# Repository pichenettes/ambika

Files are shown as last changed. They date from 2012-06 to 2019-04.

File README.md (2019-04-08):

# Ambika
## A hybrid MIDI polysynth and voicecard host.

Ambika consists of a compact motherboard serving as a "host" for up to 6 sound synthesis voicecard. While this design is primarily intended to be a flexible hybrid polysynth, it could also be used as a drum module/drum machine.

The motherboard comprises 6 audio outputs, each one connected to a voicecard ; a global mono output ; a pair of MIDI input/output ; a SD card slot ; a 5V/8V/-8V power supply capable of delivering 150mA on the 8V rails and 350mA on the 5V rail ; the master MCU and the user interface elements. The voicecards (a pair of each being attached to the 3 voicecard ports) are SPI slaves, they receive note and modulation data from the motherboard ; and output monophonic audio, ideally 1V pp.

3 designs of voicecards implementing a refined version of the Shruthi-1 engine are provided. Each of those use a different filter (4-Pole with LM13700, 4-Pole with SSM2164, 2-Pole SVF with SSM2164).

Original developer: Emilie Gillet (emilie.o.gillet@gmail.com)

The firmware is released under a GPL3.0 license. It includes a variant of the formant synthesis algorithm used in Peter Knight's Cantarino speech synthesizer.

The PCB layouts and schematics, documentation, analyses, simulations and 3D models are released under a Creative Commons cc-by-sa 3.0 license.

# Build

You'll need:
- make
- gcc-avr
- avr-libc
- avrdude
- python

On Ubuntu:
```
    sudo apt-get install gcc-avr make avr-libc
```

Next, you'll need to grab the projects this repo depends on.
```
    git submodule update --init
```

Once you've got that all settled, you'll need to change the path to `avr-gcc` in avrlib/makefile.mk
to match the path on your system.

```
    export AVRPATH=`which avr-gcc`
    sed "s|AVRLIB_TOOLS_PATH ?=.*|AVRLIB_TOOLS_PATH \?= `dirname $AVRPATH`/|" avrlib/makefile.mk > mkfiletmp
    mv mkfiletmp avrlib/makefile.mk
```

Then, for voice card `elf` files:

```
    make all
```

And for voice card `bin` files:
```
    make bin
```

For motherboard `elf` files:
```
    make bootstrap_controller
```

For motherboard `bin` files:
```
    make -f controller/makefile bin
```

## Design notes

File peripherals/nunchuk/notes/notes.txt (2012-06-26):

C: change program
long press on C: enable/disable program change on C

4/ Drummer (logotone: C C C CC C)

Accelerometer hit: Play C1
Accelerometer hit + Z: Play D1

5/ Controller (C with modulations)

joystick DOWN/UP: CTRL1
joystick LEFT/RIGHT: CTRL2
Z + joystick DOWN/UP: CTRL3
Z + joystick LEFT/RIGHT: CTRL4

6/ Firestarter

joystick DOWN/UP: Cutoff drive
joystick LEFT/RIGHT: Resonance drive
Z: start
Z + joystick DOWN/UP: transpose +/- 2
Z + joystick LEFT/RIGHT: transpose +/- 1

2/ Navigator (logotone: C G C)

Z: play note. On release: make current note center note
Z + joystick DOWN/UP: note +/- 7 12
Z + joystick LEFT/RIGHT: note +/- 2 9

Accelerometer hit: play current note

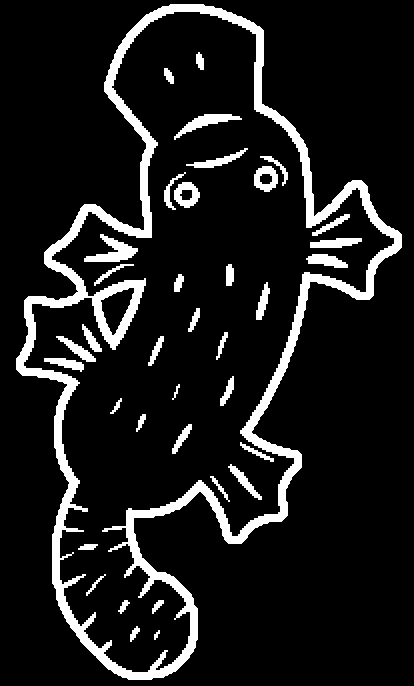
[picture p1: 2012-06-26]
peripherals/nunchuk/hardware_design/pcb/platypus.bmp

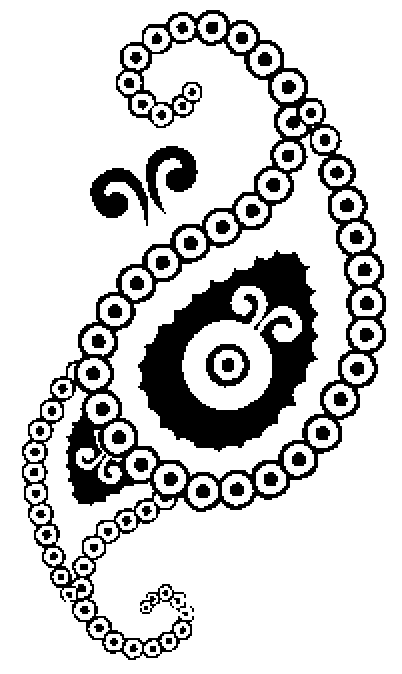
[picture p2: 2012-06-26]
voicecard/hardware_design/pcb/lapino.bmp

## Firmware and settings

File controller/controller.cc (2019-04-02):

// Copyright 2011 Emilie Gillet.
//
// Author: Emilie Gillet (emilie.o.gillet@gmail.com)
//
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

#include <avr/interrupt.h>

#include "avrlib/boot.h"
#include "avrlib/serial.h"
#include "avrlib/watchdog_timer.h"

#include "controller/midi_dispatcher.h"
#include "controller/multi.h"
#include "controller/resources.h"
#include "controller/storage.h"
#include "controller/system_settings.h"
#include "controller/ui.h"
#include "controller/voicecard_tx.h"

#include "midi/midi.h"

using namespace ambika;
using namespace avrlib;
using namespace midi;

// Midi input.
MidiIO midi_io;
MidiBuffer midi_in_buffer;
MidiStreamParser<MidiDispatcher> midi_parser;

inline void FlushMidiOut() {
  // Try to flush the high priority buffer first.
  if (midi_dispatcher.readable_high_priority()) {
    if (midi_io.writable()) {
      midi_io.Overwrite(midi_dispatcher.ImmediateReadHighPriority());
    }
  } else {
    if (midi_dispatcher.readable_low_priority()) {
      if (midi_io.writable()) {
        midi_io.Overwrite(midi_dispatcher.ImmediateReadLowPriority());
      }
    }
  }
}

inline void PollMidiIn() {
  if (midi_io.readable()) {
    midi_in_buffer.NonBlockingWrite(midi_io.ImmediateRead());
  }
}

// This timer is responsible for:
// - Flushing the MIDI out data, at a rate of 4.882kHz
// - Debouncing the switches and refreshing the LCD at 4.882kHz
// - Ticking the ms sys clock at 4.882kHz / 4 = 1.221 kHz
ISR(TIMER1_OVF_vect, ISR_NOBLOCK) {
  static uint8_t cycle = 0;
  PollMidiIn();
  FlushMidiOut();
  ui.Poll();
  if ((cycle & 3) == 0) {
    TickSystemClock();
  }
  ++cycle;
  if (cycle == 48) {
    cycle = 0;
    storage.Tick();
  }
}

// This timer is responsible for keeping track of time for the internal clock,
// and for sending data to the voicecards.
ISR(TIMER2_OVF_vect) {
  multi.Tick();
  voicecard_tx.SendBytes();
}

void Init() {
  sei();
  UCSR0B = 0;
  UCSR1B = 0;
  ResetWatchdog();
  Gpio<PortC, 0>::set_mode(DIGITAL_OUTPUT);
  system_settings.Init(false);
  midi_io.Init();
  
  Timer<1>::set_prescaler(2);
  Timer<1>::set_mode(TIMER_PWM_PHASE_CORRECT);
  Timer<2>::set_prescaler(1);
  Timer<2>::set_mode(TIMER_PWM_PHASE_CORRECT);
  Timer<2>::Start();
  
  ui.Init();
  Timer<1>::Start();

  voicecard_tx.Init();
  voicecard_tx.SyncAllVoices();
  if (!system_settings.data().voicecard_leds) {
    voicecard_tx.LightsOut();
  }
  if (ui.shifted()) {
    system_settings.Init(true);
  }
  multi.Init(ui.shifted());

  storage.Init();
}

int main(void) {
  Init();
  ui.FlushEvents();
  while (1) {
    // Do some MIDI.
    while (midi_in_buffer.readable()) {
      midi_parser.PushByte(midi_in_buffer.ImmediateRead());
    }
    // Do some LFOs and clocks.
    multi.UpdateClocks();
    // Do some display.
    ui.DoEvents();
  }
}

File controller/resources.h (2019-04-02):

// Copyright 2009 Emilie Gillet.
//
// Author: Emilie Gillet (emilie.o.gillet@gmail.com)
//
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
// -----------------------------------------------------------------------------
//
// Resources definitions.
//
// Automatically generated with:
// make resources


#ifndef CONTROLLER_RESOURCES_H_
#define CONTROLLER_RESOURCES_H_


#include "avrlib/base.h"

#include <avr/pgmspace.h>


#include "avrlib/resources_manager.h"

namespace ambika {

typedef uint16_t ResourceId;

extern const prog_char* const string_table[];

extern const prog_uint16_t* const lookup_table_table[];

extern const prog_uint8_t* const character_table[];

extern const prog_uint8_t* const waveform_table[];

extern const prog_uint16_t lut_res_lfo_increments[] PROGMEM;
extern const prog_uint16_t lut_res_scale_just[] PROGMEM;
extern const prog_uint16_t lut_res_scale_pythagorean[] PROGMEM;
extern const prog_uint16_t lut_res_scale_1_4_eb[] PROGMEM;
extern const prog_uint16_t lut_res_scale_1_4_e[] PROGMEM;
extern const prog_uint16_t lut_res_scale_1_4_ea[] PROGMEM;
extern const prog_uint16_t lut_res_scale_bhairav[] PROGMEM;
extern const prog_uint16_t lut_res_scale_gunakri[] PROGMEM;
extern const prog_uint16_t lut_res_scale_marwa[] PROGMEM;
extern const prog_uint16_t lut_res_scale_shree[] PROGMEM;
extern const prog_uint16_t lut_res_scale_purvi[] PROGMEM;
extern const prog_uint16_t lut_res_scale_bilawal[] PROGMEM;
extern const prog_uint16_t lut_res_scale_yaman[] PROGMEM;
extern const prog_uint16_t lut_res_scale_kafi[] PROGMEM;
extern const prog_uint16_t lut_res_scale_bhimpalasree[] PROGMEM;
extern const prog_uint16_t lut_res_scale_darbari[] PROGMEM;
extern const prog_uint16_t lut_res_scale_rageshree[] PROGMEM;
extern const prog_uint16_t lut_res_scale_khamaj[] PROGMEM;
extern const prog_uint16_t lut_res_scale_mimal[] PROGMEM;
extern const prog_uint16_t lut_res_scale_parameshwari[] PROGMEM;
extern const prog_uint16_t lut_res_scale_rangeshwari[] PROGMEM;
extern const prog_uint16_t lut_res_scale_gangeshwari[] PROGMEM;
extern const prog_uint16_t lut_res_scale_kameshwari[] PROGMEM;
extern const prog_uint16_t lut_res_scale_pa__kafi[] PROGMEM;
extern const prog_uint16_t lut_res_scale_natbhairav[] PROGMEM;
extern const prog_uint16_t lut_res_scale_m_kauns[] PROGMEM;
extern const prog_uint16_t lut_res_scale_bairagi[] PROGMEM;
extern const prog_uint16_t lut_res_scale_b_todi[] PROGMEM;
extern const prog_uint16_t lut_res_scale_chandradeep[] PROGMEM;
extern const prog_uint16_t lut_res_scale_kaushik_todi[] PROGMEM;
extern const prog_uint16_t lut_res_scale_jogeshwari[] PROGMEM;
extern const prog_uint16_t lut_res_arpeggiator_patterns[] PROGMEM;
extern const prog_uint16_t lut_res_groove_swing[] PROGMEM;
extern const prog_uint16_t lut_res_groove_shuffle[] PROGMEM;
extern const prog_uint16_t lut_res_groove_push[] PROGMEM;
extern const prog_uint16_t lut_res_groove_lag[] PROGMEM;
extern const prog_uint16_t lut_res_groove_human[] PROGMEM;
extern const prog_uint16_t lut_res_groove_monkey[] PROGMEM;
extern const prog_uint8_t chr_res_special_characters[] PROGMEM;
extern const prog_uint8_t wav_res_lfo_waveforms[] PROGMEM;
#define STR_RES_WAVEFORM 0  // waveform
#define STR_RES_PARAMETER 1  // parameter
#define STR_RES_RANGE 2  // range
#define STR_RES_TUNE 3  // tune
#define STR_RES_OSC_MIX 4  // osc mix
#define STR_RES_SUB_OSC_ 5  // sub osc.
#define STR_RES_CROSSMOD_ 6  // crossmod.
#define STR_RES_OPERATOR 7  // operator
#define STR_RES_AMOUNT 8  // amount
#define STR_RES_RESONANCE 9  // resonance
#define STR_RES_MODE 10  // mode
#define STR_RES_ENV2TVCF 11  // env2~vcf
#define STR_RES_LFO2TVCF 12  // lfo2~vcf
#define STR_RES_ATTACK 13  // attack
#define STR_RES_DECAY 14  // decay
#define STR_RES_SUSTAIN 15  // sustain
#define STR_RES_RELEASE 16  // release
#define STR_RES_TRIGGER 17  // trigger
#define STR_RES_RATE 18  // rate
#define STR_RES_LFO_EG 19  // lfo/eg
#define STR_RES_VOICE_LFO 20  // voice lfo
#define STR_RES_SOURCE 21  // source
#define STR_RES_DESTINATION 22  // destination
#define STR_RES_IN1 23  // in1
#define STR_RES_IN2 24  // in2
#define STR_RES_MODULATION 25  // modulation
#define STR_RES_MODUL_ 26  // modul.
#define STR_RES__MODULATION 27  // modulation
#define STR_RES_MODIFIER 28  // modifier
#define STR_RES_MODIF_ 29  // modif.
#define STR_RES_VOLUME 30  // volume
#define STR_RES_OCTAVE 31  // octave
#define STR_RES_SPREAD 32  // spread
#define STR_RES_LEGATO 33  // legato
#define STR_RES_PORTAMENTO 34  // portamento
#define STR_RES_ARP_SEQ 35  // arp/seq
#define STR_RES_RAGA 36  // raga
#define STR_RES_DIRECTION 37  // direction
#define STR_RES_PATTERN 38  // pattern
#define STR_RES_CHANNEL 39  // channel
#define STR_RES_PART 40  // part
#define STR_RES_BPM 41  // bpm
#define STR_RES_LTCH 42  // ltch
#define STR_RES_LATCH 43  // latch
#define STR_RES_LOW 44  // low
#define STR_RES_HIGH 45  // high
#define STR_RES_GRID 46  // grid
#define STR_RES_SEQ1_LEN 47  // seq1 len
#define STR_RES_SEQ2_LEN 48  // seq2 len
#define STR_RES_PATT_LEN 49  // patt len
#define STR_RES_LEN1 50  // len1
#define STR_RES_LEN2 51  // len2
#define STR_RES_LENP 52  // lenp
#define STR_RES_GROOVE 53  // groove
#define STR_RES_MIDI 54  // midi
#define STR_RES_SNAP 55  // snap
#define STR_RES_HELP 56  // help
#define STR_RES_AUTO_BACKUP 57  // auto backup
#define STR_RES_LEDS 58  // leds
#define STR_RES_CARD_LEDS 59  // card leds
#define STR_RES_SWAP_COLORS 60  // swap colors
#define STR_RES_INPT_FILTER 61  // inpt filter
#define STR_RES_OUTP_MODE 62  // outp mode
#define STR_RES_EXT 63  // ext
#define STR_RES_OMNI 64  // omni
#define STR_RES_AMNT 65  // amnt
#define STR_RES_SRCE 66  // srce
#define STR_RES_OCT 67  // oct
#define STR_RES_SPRD 68  // sprd
#define STR_RES_A_SQ 69  // a/sq
#define STR_RES_OCTV 70  // octv
#define STR_RES_OFF 71  // off
#define STR_RES_ON 72  // on
#define STR_RES_NONE 73  // none
#define STR_RES_SAW 74  // saw
#define STR_RES_SQUARE 75  // square
#define STR_RES_TRIANGLE 76  // triangle
#define STR_RES_SINE 77  // sine
#define STR_RES_ZSAW 78  // zsaw
#define STR_RES_LPZSAW 79  // lpzsaw
#define STR_RES_PKZSAW 80  // pkzsaw
#define STR_RES_BPZSAW 81  // bpzsaw
#define STR_RES_HPZSAW 82  // hpzsaw
#define STR_RES_LPZPULSE 83  // lpzpulse
#define STR_RES_PKZPULSE 84  // pkzpulse
#define STR_RES_BPZPULSE 85  // bpzpulse
#define STR_RES_HPZPULSE 86  // hpzpulse
#define STR_RES_ZTRIANGLE 87  // ztriangle
#define STR_RES_PAD 88  // pad
#define STR_RES_FM 89  // fm
#define STR_RES_8BITS 90  // 8bits
#define STR_RES_PWM 91  // pwm
#define STR_RES_NOISE 92  // noise
#define STR_RES_VOWEL 93  // vowel
#define STR_RES_MALE 94  // male
#define STR_RES_FEMALE 95  // female
#define STR_RES_CHOIR 96  // choir
#define STR_RES_TAMPURA 97  // tampura
#define STR_RES_BOWED 98  // bowed
#define STR_RES_CELLO 99  // cello
#define STR_RES_VIBES 100  // vibes
#define STR_RES_SLAP 101  // slap
#define STR_RES_EPIANO 102  // epiano
#define STR_RES_ORGAN 103  // organ
#define STR_RES_WAVES 104  // waves
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

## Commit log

2012-06-29 Added more programs
    [Mobo-v07.brd]
2012-07-05 PCB tweaks
    [Mobo-v07.brd, Mobo-v07.sch, Voicecard-SVF-v04.brd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]
2012-07-05 New version of mobo PCB with simplified output stage and 808-style individual outputs
    [Mobo-v07.brd, Mobo-v07.sch, Mobo-v08.brd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]
2012-07-05 Changed resistors in output stage
    [Mobo-v08.brd, Mobo-v08.sch]
2012-07-05 Removed previous version of mobo
    [Mobo-v07.brd, Mobo-v07.sch]
2012-08-13 Added case file
2012-10-19 Changed parts/voices LED order, from column major to row major
2012-10-19 Bootloader crash detection more tolerant
    [bootloader.cc]
2012-11-15 Added extra settings menu for swapping LEDs colors
    [resources.h, ui.cc]
2013-01-04 Fix pedal release bug
    [note_stack.h]
2013-10-24 Ambika mobo, PCB tweaks
    [Mobo-v08.brd, Mobo-v08.sch, Mobo-v09.brd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]
2013-11-23 Performance page should not be reachable with the encoder because it takes control of the inc/dec handler to change the note
2013-11-26 Do not send the poly mode = chain message
2014-03-03 4P voicecard: new logo
    [Voicecard-4P-v01.brd, Voicecard-SMR-v04.brd]
2014-03-17 4P PCB
    [Voicecard-4P-v01.brd]
2014-11-28 Ambika dummy event bug
    [ui.cc]
2019-04-02 Updated name
    [Mobo-v09.brd, Mobo-v09.sch, Voicecard-4P-v01.brd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]

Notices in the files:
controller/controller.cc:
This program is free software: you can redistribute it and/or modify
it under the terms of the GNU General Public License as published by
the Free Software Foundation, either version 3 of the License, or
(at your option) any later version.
